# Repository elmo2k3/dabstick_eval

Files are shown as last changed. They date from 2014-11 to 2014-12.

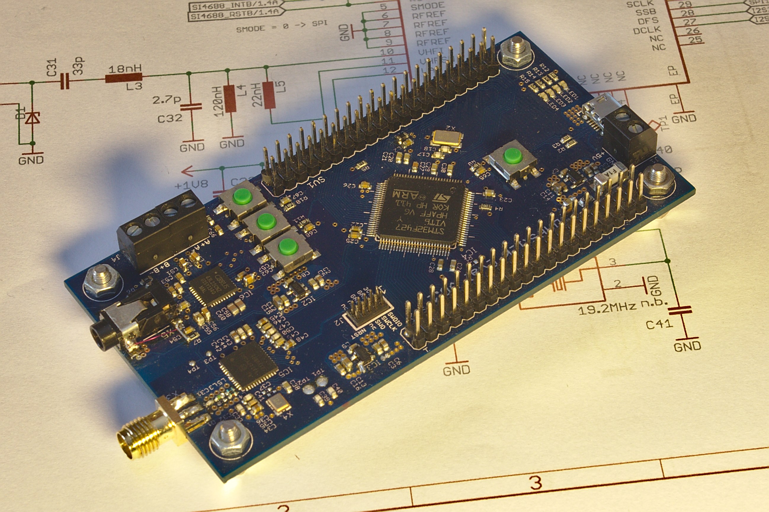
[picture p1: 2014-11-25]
pics/dabstick_v1.jpg

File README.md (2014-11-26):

# DABStick Eval - Experimental board for SI4688 FM/DAB+ receiver with STM32F4 and audio codec

![Image of DABPStick Eval v1 PCB]
(https://github.com/elmo2k3/dabstick_eval/blob/master/pics/dabstick_v1.jpg)

## Warning

This project is still work in progress

## Hardware

* STM32F427VIT6 microcontroller
  * 2MB Flash, 256KB SRAM
  * Up to 180MHz, here 168MHz
* SI4688-A10-GM FM / HD / DAB / DAB + radio receiver
* CS43L22 Audio DAC with integrated class D speaker driver
* General purpose 2x40 pin headers
* Power by USB or screw connector

## Functional overview

![Graph of functional overview]
(https://github.com/elmo2k3/dabstick_eval/blob/master/doc/DABStick_overview.png)

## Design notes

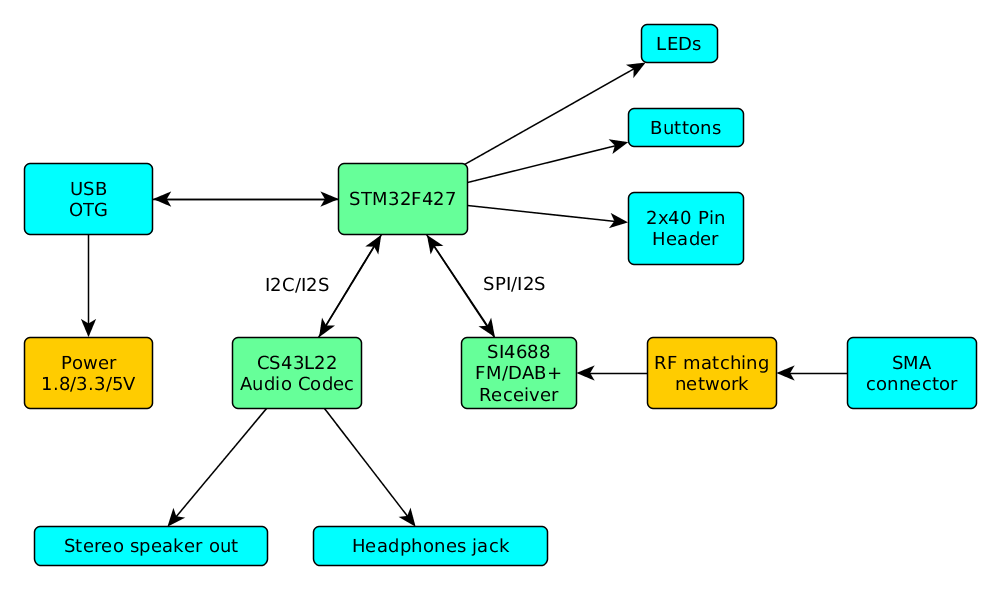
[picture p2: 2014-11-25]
doc/DABStick_overview.png

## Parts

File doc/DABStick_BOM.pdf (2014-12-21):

#name | description | footprint | total_mount_quantity storelocation | suppliers | supplierpartnrs

120NH 110MA 0402 | | L_0402 | 1 | Digikey,Farnell | 490-4091-1-ND,2212473
18NH 300MA 0402 | | L_0402 | 1 | Digikey,Farnell | 490-2626-1-ND,1343084
19.2MHZ,3.2 X 2.5 MM | CRYSTAL 19.2MHZ 10PF SMD | | 1 | Digikey,Farnell | 300-8228-1-ND,1842063
22NH 3% 0402 | | L_0402 | 1 | Digikey,Farnell | 490-6788-1-ND,1711784
8MHz 18PF SMD 5x3.2 | 4 Pads | | 1 | Digikey | 535-9720-1-ND
AKL 059-02 | Anschlussklemme 2-polig, RM3,5 | THT 3.5mm | 2 Pollin Blau 12 Reichelt | AKL 059-02
BLM15HG102SN1D | FILTER CHIP 1000 OHM 250MA 0402 | L_0402 | 1 | Digikey | 490-3999-1-ND
CS43L22-CNZ | | QFN40 | 1 | Digikey | 598-1650-ND
ESD9L5.0ST5G | TVS ESD PROT ELT 5V SOD-923 | SOD923 | 1 Biozym 1 | Digikey,Farnell | ESD9L5.0ST5GOSCT-ND,1651639
Klinkenbuchse 3.5mm PCB LUMBERG - 1503 02 - KUPPLUNG BUCHSE, SMD 3.5MM | 1 | Farnell | 1216979
LD3985M25R | IC REG LDO 2.5V 0.15A SOT23-5 | SOT23-5 | 1 | Digikey | 497-4254-1-ND
LD3985M33R | IC REG LDO 3.3V 0.15A SOT23-5 | SOT23-5 | 1 | Digikey | 497-3504-1-ND
SI4688-A10-GM | | QFN48 | 1 | Arrow | SI4688-A10-GM
STM32F427VIT6 | ARM Mikrocontroller - MCU 32B ARM Cortex-M4 LQFP100 | 1 | Farnell | 2333369
TPS79318DBVR | IC REG LDO 1.8V 0.2A SOT23-5 | SOT23-5 | 1 | Digikey,Farnell | 296-12155-1-ND,1652374

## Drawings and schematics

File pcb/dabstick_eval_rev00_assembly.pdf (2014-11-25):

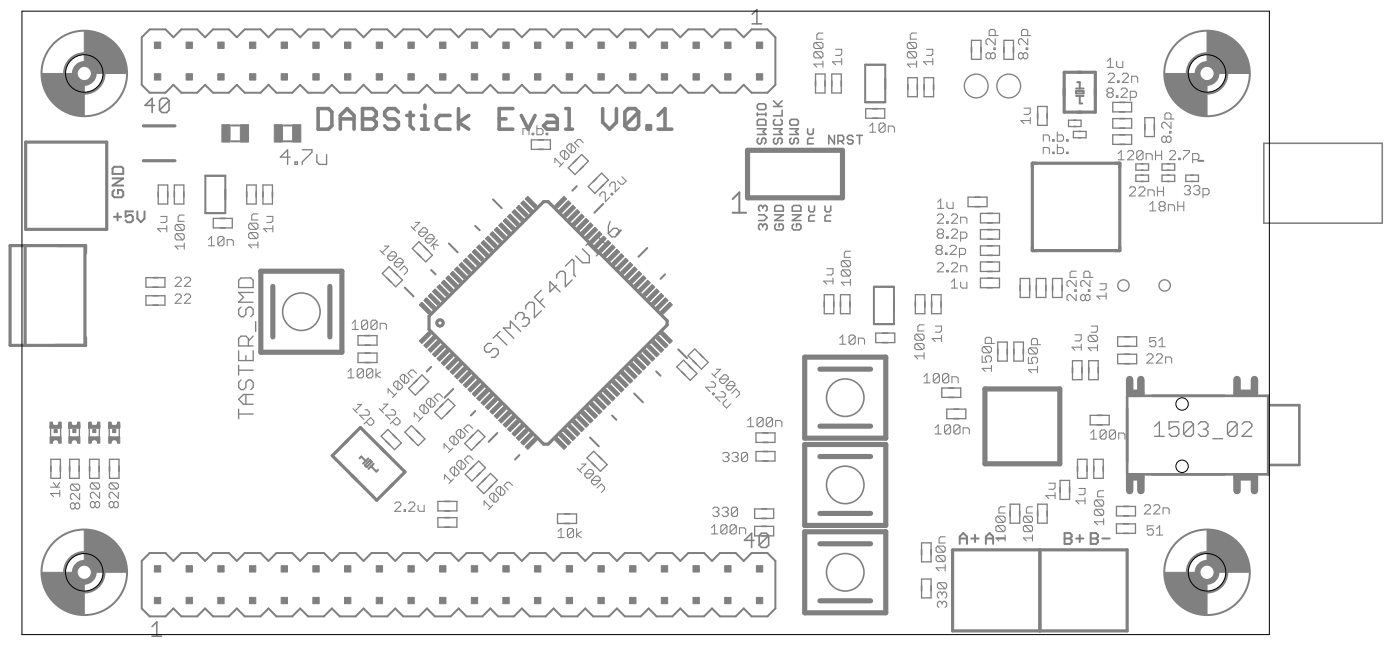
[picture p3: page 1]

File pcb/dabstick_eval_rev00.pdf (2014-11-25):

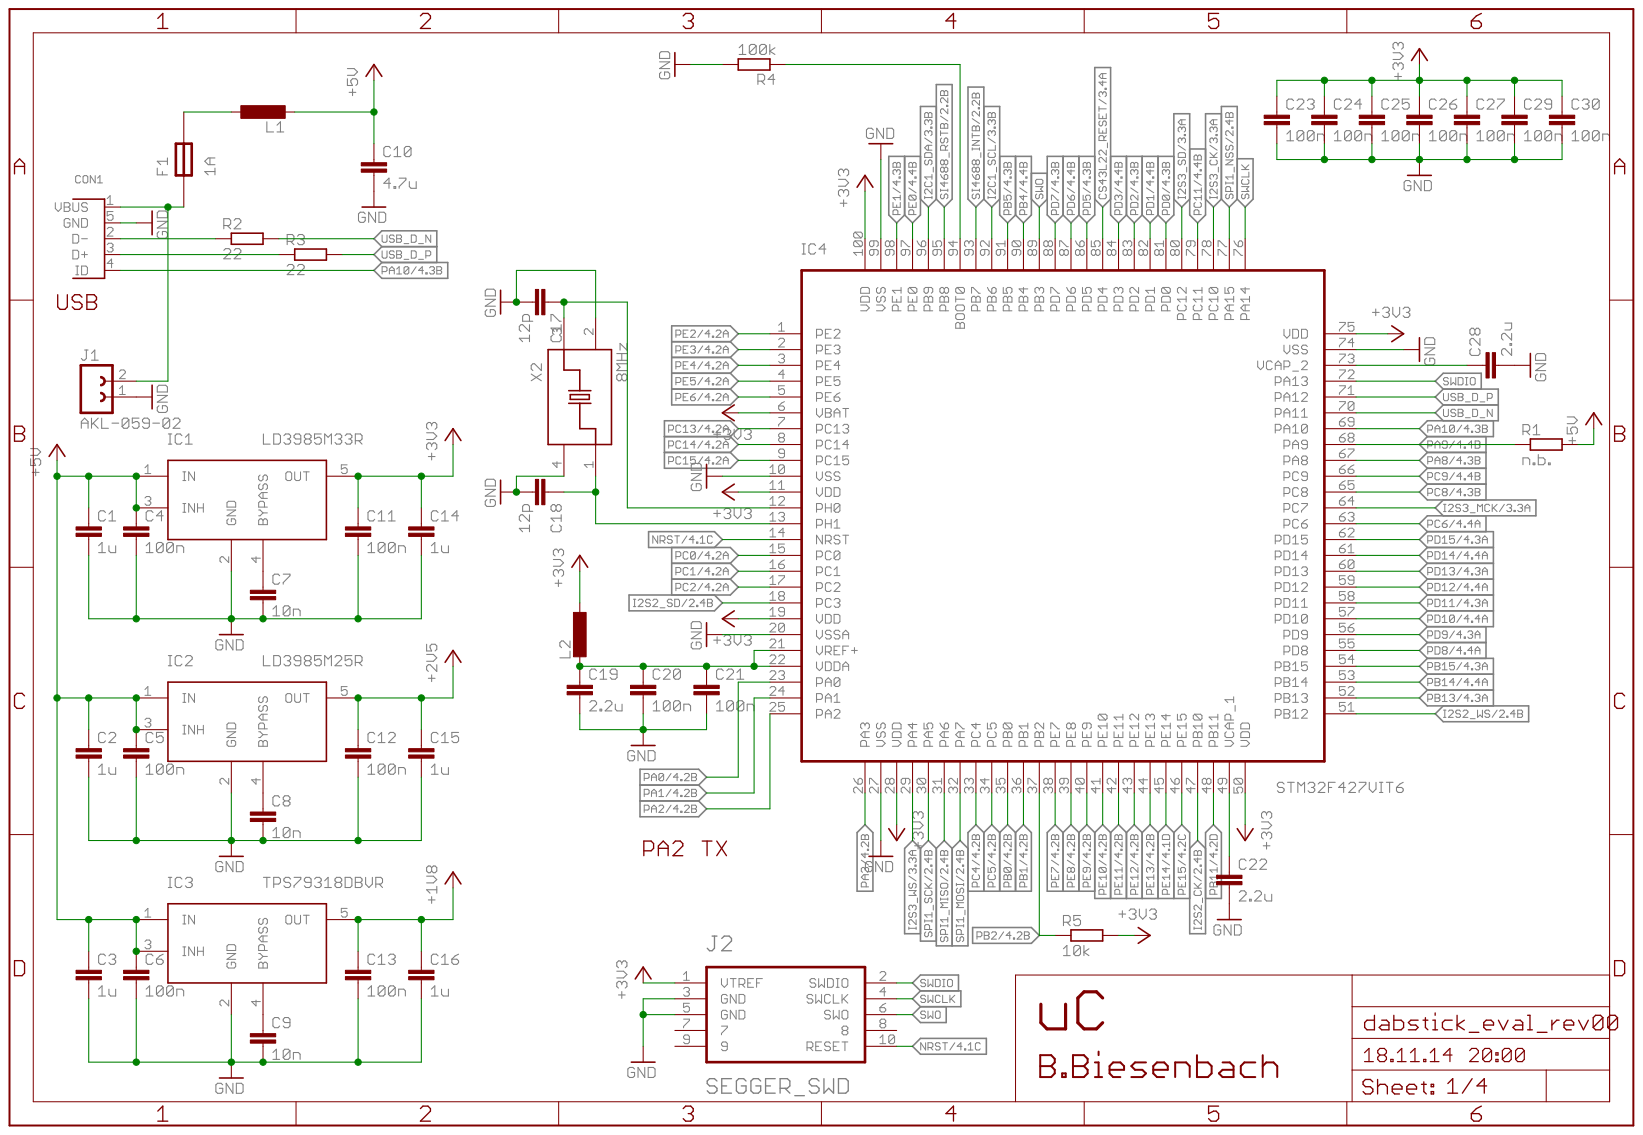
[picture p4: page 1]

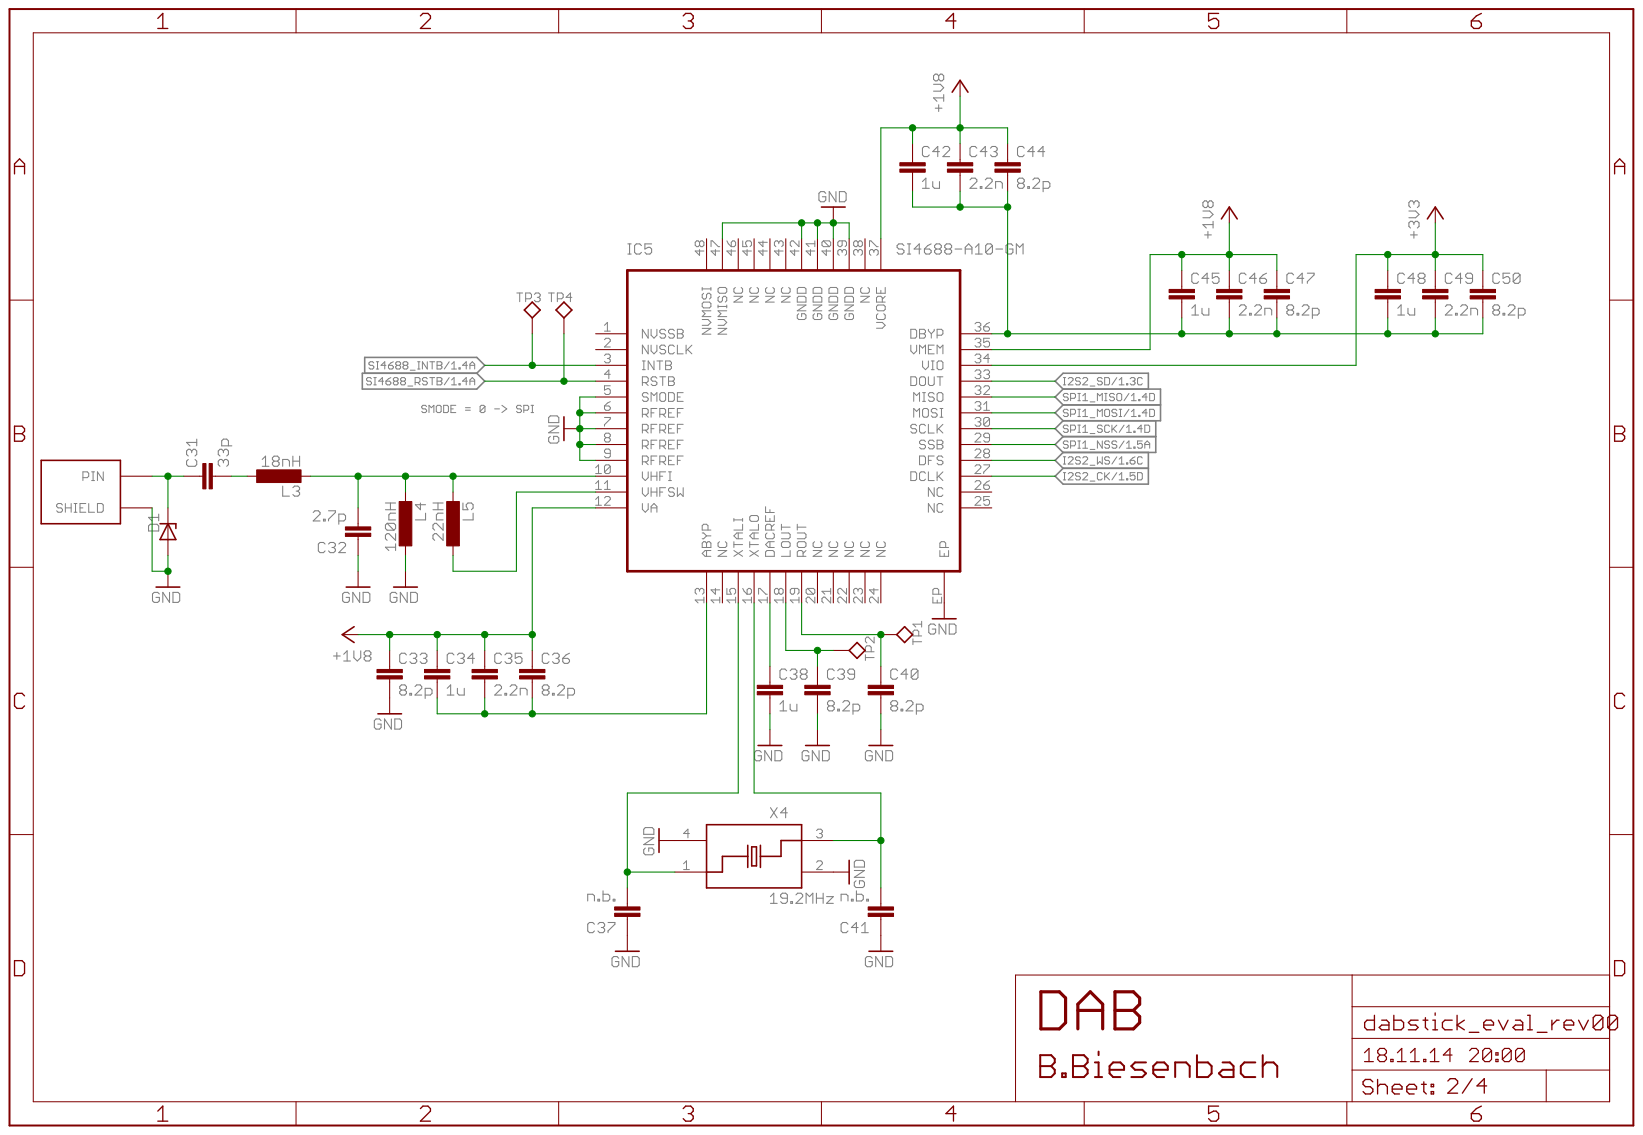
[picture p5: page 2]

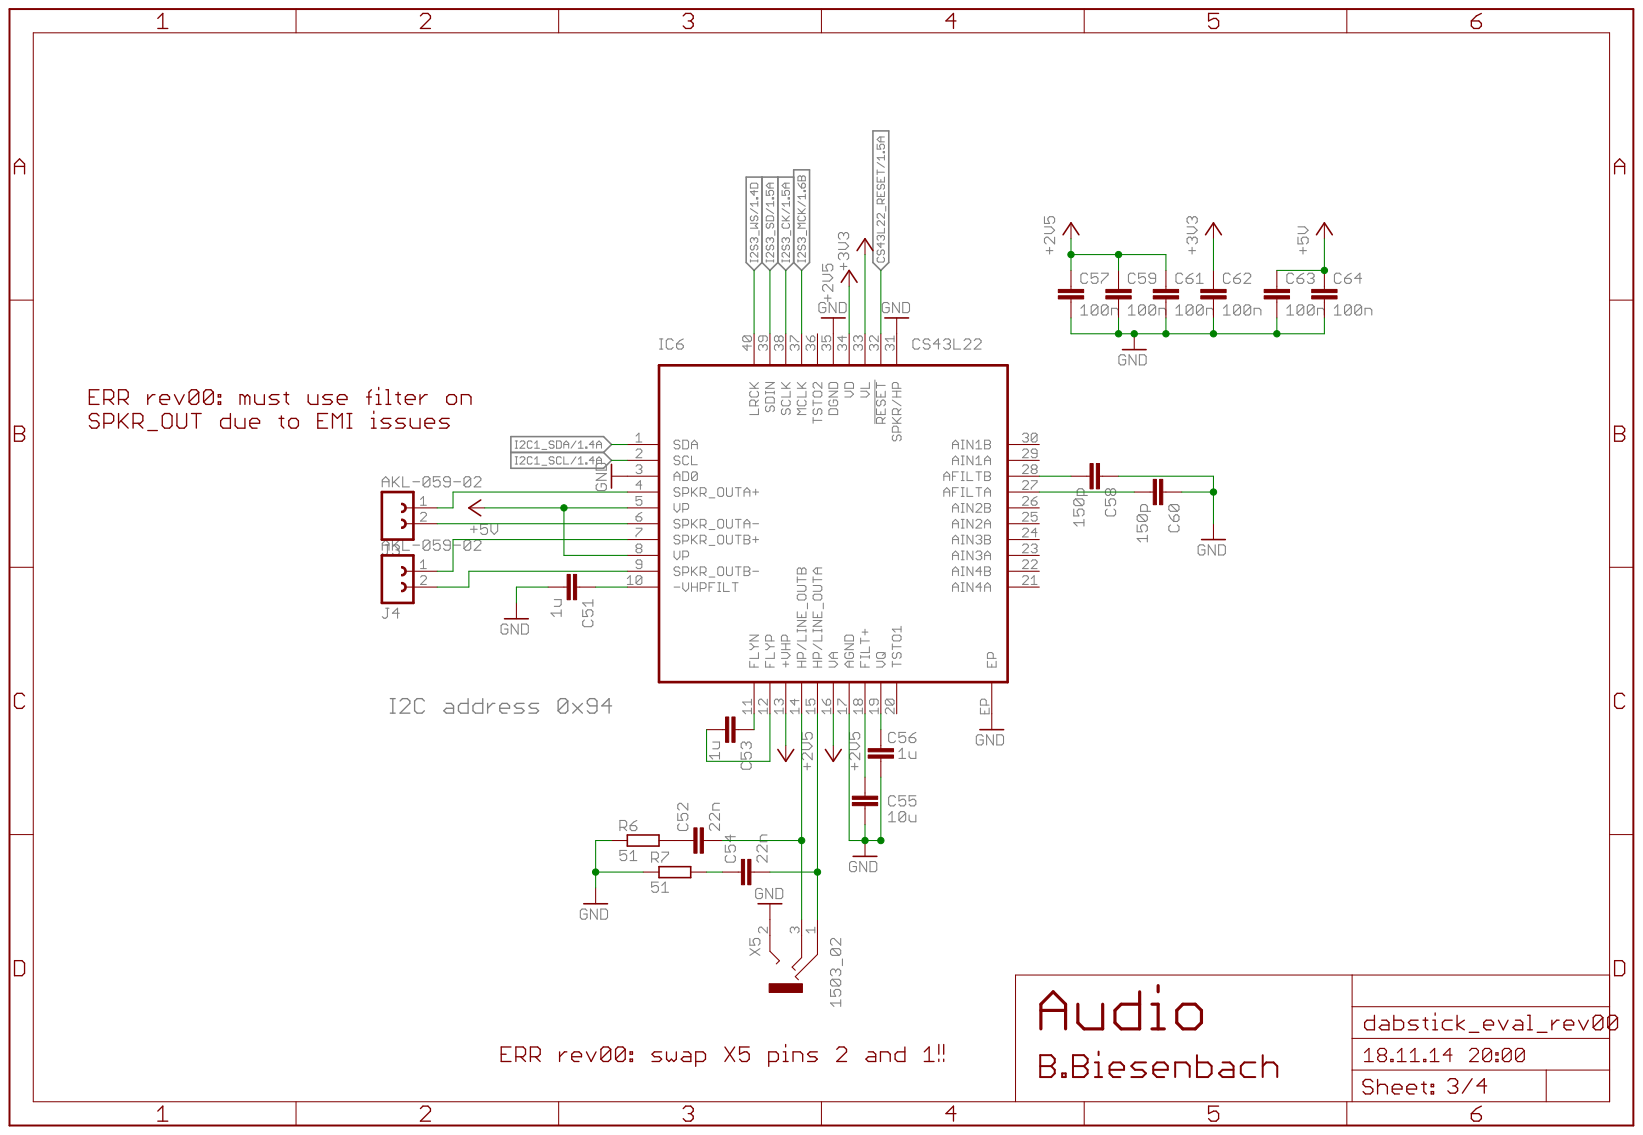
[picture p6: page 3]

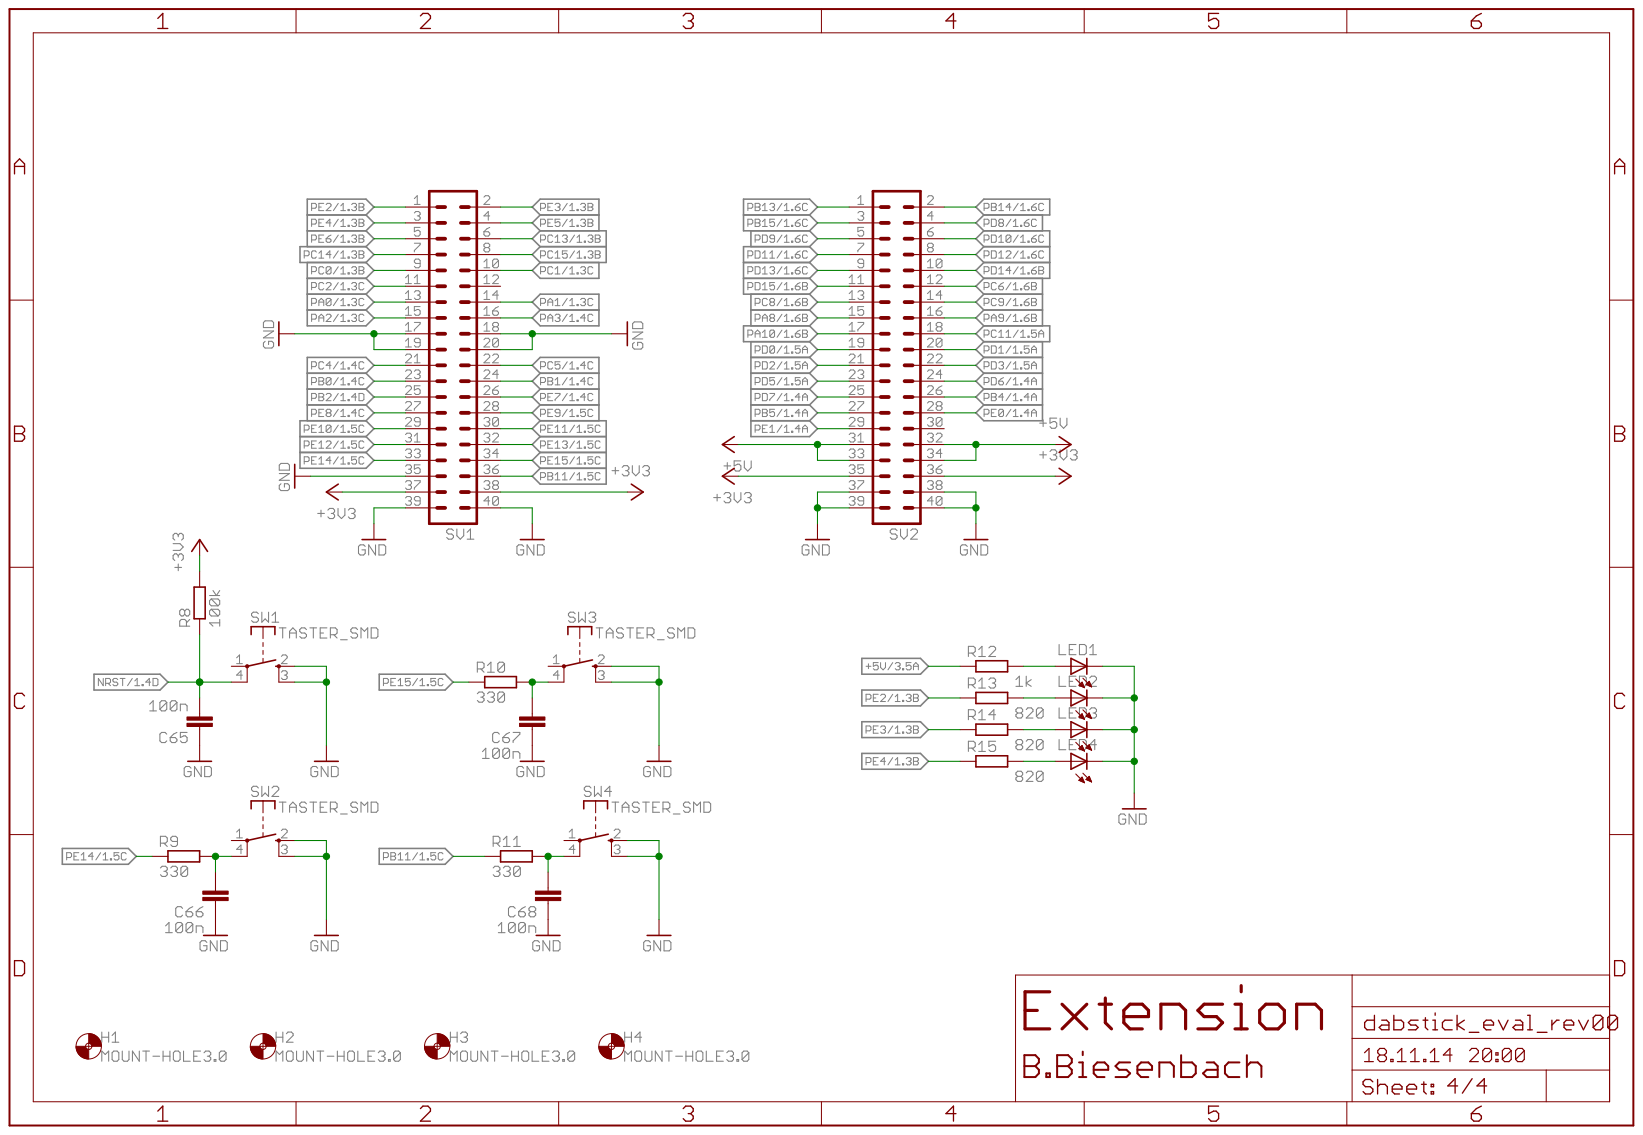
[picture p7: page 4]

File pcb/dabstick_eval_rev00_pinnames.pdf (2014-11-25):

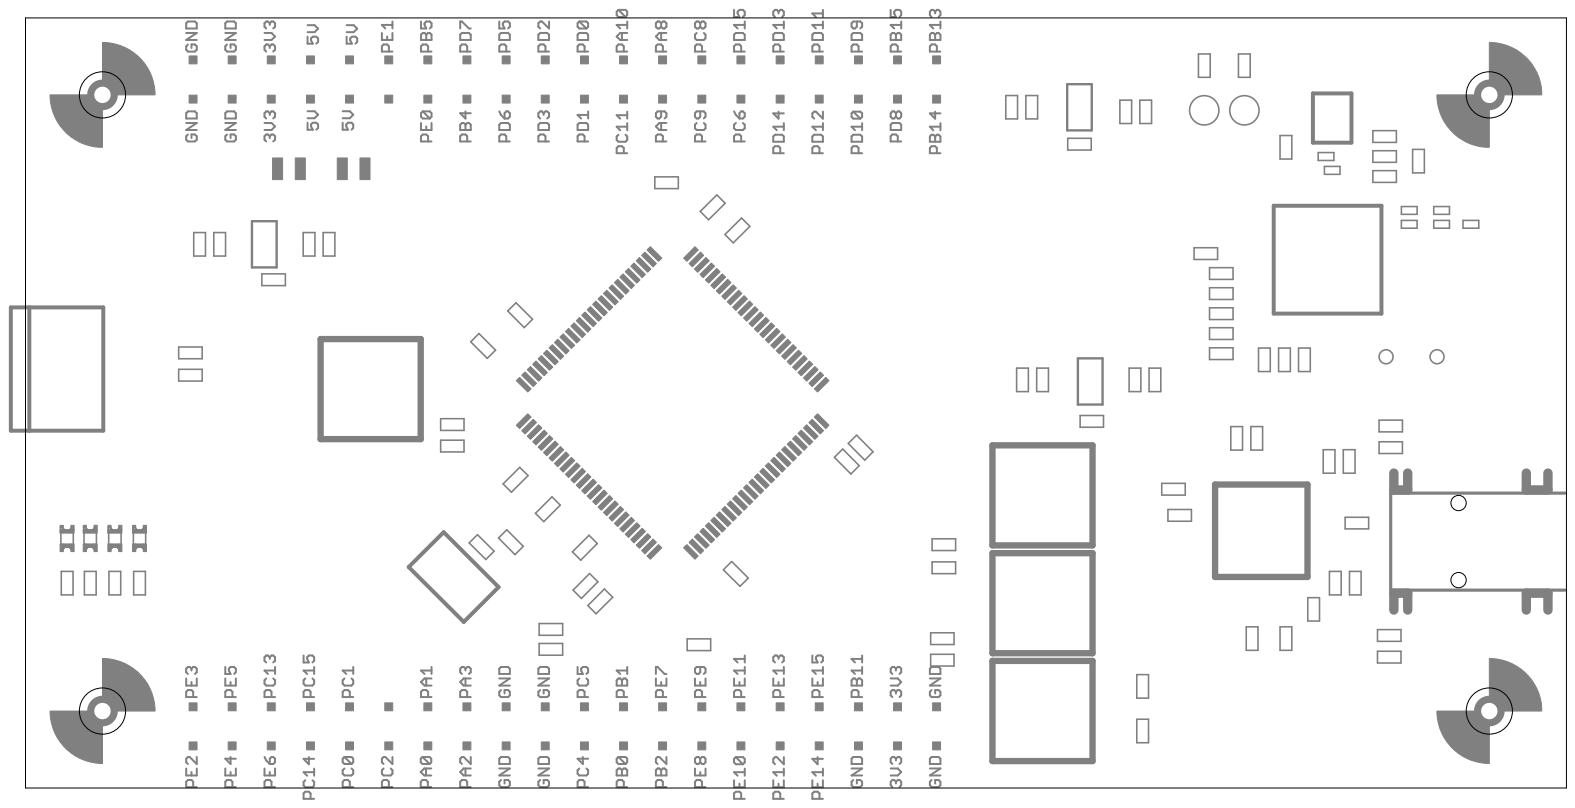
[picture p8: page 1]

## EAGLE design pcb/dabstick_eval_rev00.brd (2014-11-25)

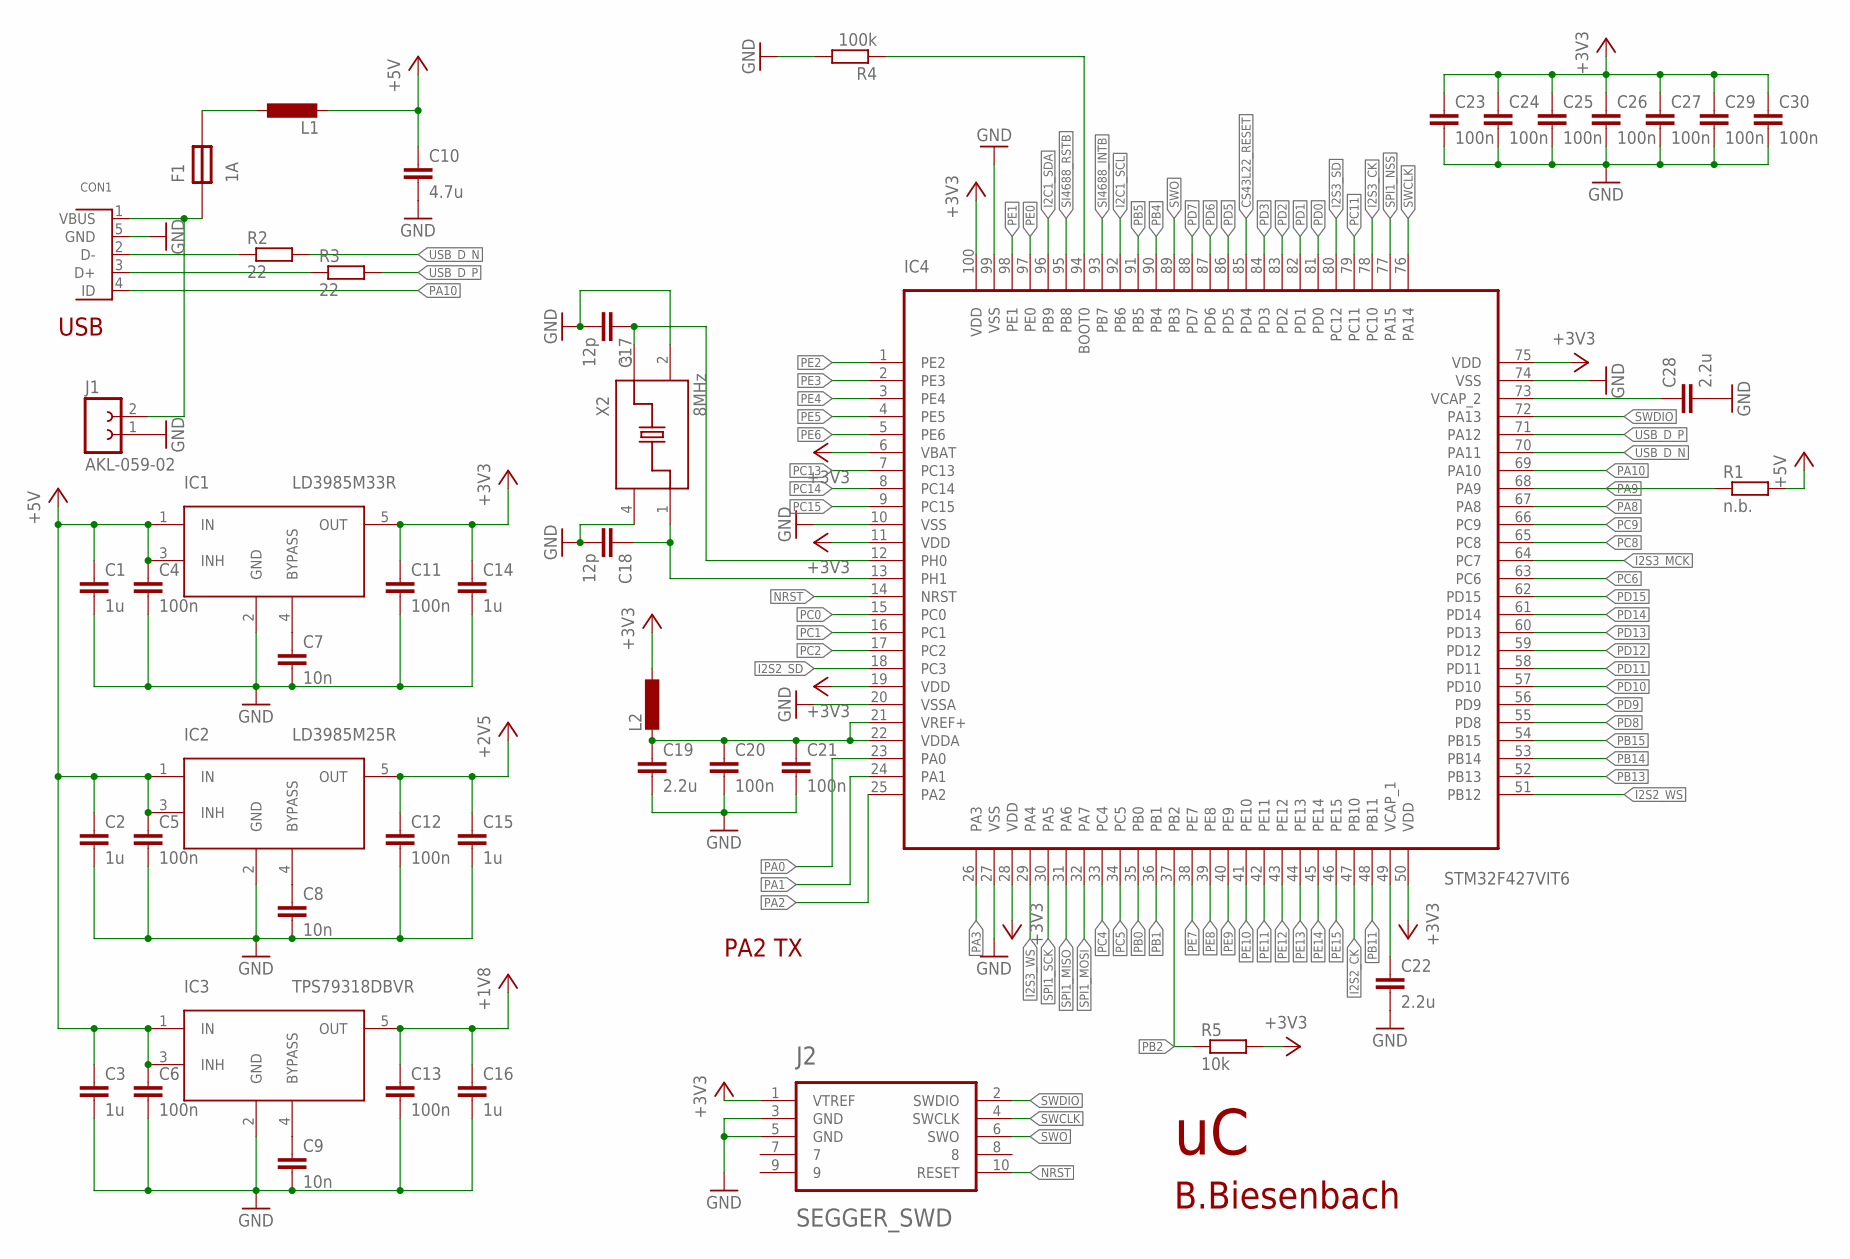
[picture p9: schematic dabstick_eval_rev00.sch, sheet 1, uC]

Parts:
C1, C2, C3, C14, C15, C16: 1u; SMD0603
C4, C5, C6, C11, C12, C13, C20, C21, C23, C24, C25, C26, C27, C29, C30: 100n; SMD0603
C7, C8, C9: 10n; SMD0603
C10: 4.7u; 0805
C17, C18: 12p; SMD0603
C19, C22, C28: 2.2u; SMD0603
CON1: USB; USB-B-MICRO-SMT
F1: 1A; SMD_FUSE
IC1: LD3985M33R; SOT23-5
IC2: LD3985M25R; SOT23-5
IC3: TPS79318DBVR; SOT23-5
IC4: STM32F427VIT6; LQFP100
J1: AKL-059-02
J2: SEGGER_SWD; HEADER_10_1.27
L1: L08050805; 0805
L2: L0603; SMD0603
R1: n.b.; SMD0603
R2, R3: 22; SMD0603
R4: 100k; SMD0603
R5: 10k; SMD0603
X2: 8MHz; XTAL_3.2X5

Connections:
+1V8: C13.1, C16.1, IC3.5 (OUT); also elsewhere on the board
+2V5: C12.1, C15.1, IC2.5 (OUT); also elsewhere on the board
+3V3: C11.1, C14.1, C23.1, C24.1, C25.1, C26.1, C27.1, C29.1, C30.1, IC1.5 (OUT), IC4.6 (VBAT), IC4.11 (VDD), IC4.19 (VDD), IC4.28 (VDD), IC4.50 (VDD), IC4.75 (VDD), IC4.100 (VDD), J2.1 (VTREF), L2.1, R5.2; also elsewhere on the board
+5V: C1.1, C2.1, C3.1, C4.1, C5.1, C6.1, C10.1, IC1.1 (IN), IC1.3 (INH), IC2.1 (IN), IC2.3 (INH), IC3.1 (IN), IC3.3 (INH), L1.2, R1.2; also elsewhere on the board
CS43L22_RESET: IC4.85 (PD4); also elsewhere on the board
GND: C1.2, C2.2, C3.2, C4.2, C5.2, C6.2, C7.2, C8.2, C9.2, C10.2, C11.2, C12.2, C13.2, C14.2, C15.2, C16.2, C17.2, C18.2, C19.2, C20.2, C21.2, C22.2, C23.2, C24.2, C25.2, C26.2, C27.2, C28.2, C29.2, C30.2, CON1.5 (GND), IC1.2 (GND), IC2.2 (GND), IC3.2 (GND), IC4.10 (VSS), IC4.20 (VSSA), IC4.27 (VSS), IC4.74 (VSS), IC4.99 (VSS), J1.1, J2.3 (GND), J2.5 (GND), R4.2, X2.2 (GND), X2.4 (GND); also elsewhere on the board
I2C1_SCL: IC4.92 (PB6); also elsewhere on the board
I2C1_SDA: IC4.96 (PB9); also elsewhere on the board
I2S2_CK: IC4.47 (PB10); also elsewhere on the board
I2S2_SD: IC4.18 (PC3); also elsewhere on the board
I2S2_WS: IC4.51 (PB12); also elsewhere on the board
I2S3_CK: IC4.78 (PC10); also elsewhere on the board
I2S3_MCK: IC4.64 (PC7); also elsewhere on the board
I2S3_SD: IC4.80 (PC12); also elsewhere on the board
I2S3_WS: IC4.29 (PA4); also elsewhere on the board
unnamed: C7.1, IC1.4 (BYPASS)
unnamed: C8.1, IC2.4 (BYPASS)
unnamed: C9.1, IC3.4 (BYPASS)
unnamed: C19.1, C20.1, C21.1, IC4.21 (VREF+), IC4.22 (VDDA), L2.2
unnamed: C28.1, IC4.73 (VCAP_2)
unnamed: C22.1, IC4.49 (VCAP_1)
unnamed: CON1.3 (D+), R3.1
unnamed: CON1.2 (D-), R2.1
unnamed: C18.1, IC4.13 (PH1), X2.1
unnamed: C17.1, IC4.12 (PH0), X2.3
unnamed: IC4.94 (BOOT0), R4.1
unnamed: F1.P$2, L1.1
unnamed: CON1.1 (VBUS), F1.P$1, J1.2
NRST: IC4.14 (NRST), J2.10 (RESET); also elsewhere on the board
PA0: IC4.23 (PA0); also elsewhere on the board
PA1: IC4.24 (PA1); also elsewhere on the board
PA2: IC4.25 (PA2); also elsewhere on the board
PA3: IC4.26 (PA3); also elsewhere on the board
PA8: IC4.67 (PA8); also elsewhere on the board
PA9: IC4.68 (PA9), R1.1; also elsewhere on the board
PA10: CON1.4 (ID), IC4.69 (PA10); also elsewhere on the board
PB0: IC4.35 (PB0); also elsewhere on the board
PB1: IC4.36 (PB1); also elsewhere on the board
PB2: IC4.37 (PB2), R5.1; also elsewhere on the board
PB4: IC4.90 (PB4); also elsewhere on the board
PB5: IC4.91 (PB5); also elsewhere on the board
PB11: IC4.48 (PB11); also elsewhere on the board
PB13: IC4.52 (PB13); also elsewhere on the board
PB14: IC4.53 (PB14); also elsewhere on the board
PB15: IC4.54 (PB15); also elsewhere on the board
PC0: IC4.15 (PC0); also elsewhere on the board
PC1: IC4.16 (PC1); also elsewhere on the board
PC2: IC4.17 (PC2); also elsewhere on the board
PC4: IC4.33 (PC4); also elsewhere on the board
PC5: IC4.34 (PC5); also elsewhere on the board
PC6: IC4.63 (PC6); also elsewhere on the board
PC8: IC4.65 (PC8); also elsewhere on the board
PC9: IC4.66 (PC9); also elsewhere on the board
PC11: IC4.79 (PC11); also elsewhere on the board
PC13: IC4.7 (PC13); also elsewhere on the board
PC14: IC4.8 (PC14); also elsewhere on the board
PC15: IC4.9 (PC15); also elsewhere on the board
PD0: IC4.81 (PD0); also elsewhere on the board
PD1: IC4.82 (PD1); also elsewhere on the board
PD2: IC4.83 (PD2); also elsewhere on the board
PD3: IC4.84 (PD3); also elsewhere on the board
PD5: IC4.86 (PD5); also elsewhere on the board
PD6: IC4.87 (PD6); also elsewhere on the board
PD7: IC4.88 (PD7); also elsewhere on the board
PD8: IC4.55 (PD8); also elsewhere on the board
PD9: IC4.56 (PD9); also elsewhere on the board
PD10: IC4.57 (PD10); also elsewhere on the board
PD11: IC4.58 (PD11); also elsewhere on the board
PD12: IC4.59 (PD12); also elsewhere on the board
PD13: IC4.60 (PD13); also elsewhere on the board
PD14: IC4.61 (PD14); also elsewhere on the board
PD15: IC4.62 (PD15); also elsewhere on the board
PE0: IC4.97 (PE0); also elsewhere on the board
PE1: IC4.98 (PE1); also elsewhere on the board
PE2: IC4.1 (PE2); also elsewhere on the board
PE3: IC4.2 (PE3); also elsewhere on the board
PE4: IC4.3 (PE4); also elsewhere on the board
PE5: IC4.4 (PE5); also elsewhere on the board
PE6: IC4.5 (PE6); also elsewhere on the board
PE7: IC4.38 (PE7); also elsewhere on the board
PE8: IC4.39 (PE8); also elsewhere on the board
PE9: IC4.40 (PE9); also elsewhere on the board
PE10: IC4.41 (PE10); also elsewhere on the board
PE11: IC4.42 (PE11); also elsewhere on the board
PE12: IC4.43 (PE12); also elsewhere on the board
PE13: IC4.44 (PE13); also elsewhere on the board
PE14: IC4.45 (PE14); also elsewhere on the board
PE15: IC4.46 (PE15); also elsewhere on the board
SI4688_INTB: IC4.93 (PB7); also elsewhere on the board
SI4688_RSTB: IC4.95 (PB8); also elsewhere on the board
SPI1_MISO: IC4.31 (PA6); also elsewhere on the board
SPI1_MOSI: IC4.32 (PA7); also elsewhere on the board
SPI1_NSS: IC4.77 (PA15); also elsewhere on the board
SPI1_SCK: IC4.30 (PA5); also elsewhere on the board
SWCLK: IC4.76 (PA14), J2.4 (SWCLK)
SWDIO: IC4.72 (PA13), J2.2 (SWDIO)
SWO: IC4.89 (PB3), J2.6 (SWO)
USB_D_N: IC4.70 (PA11), R2.2
USB_D_P: IC4.71 (PA12), R3.2

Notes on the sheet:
PA2 TX
B.Biesenbach

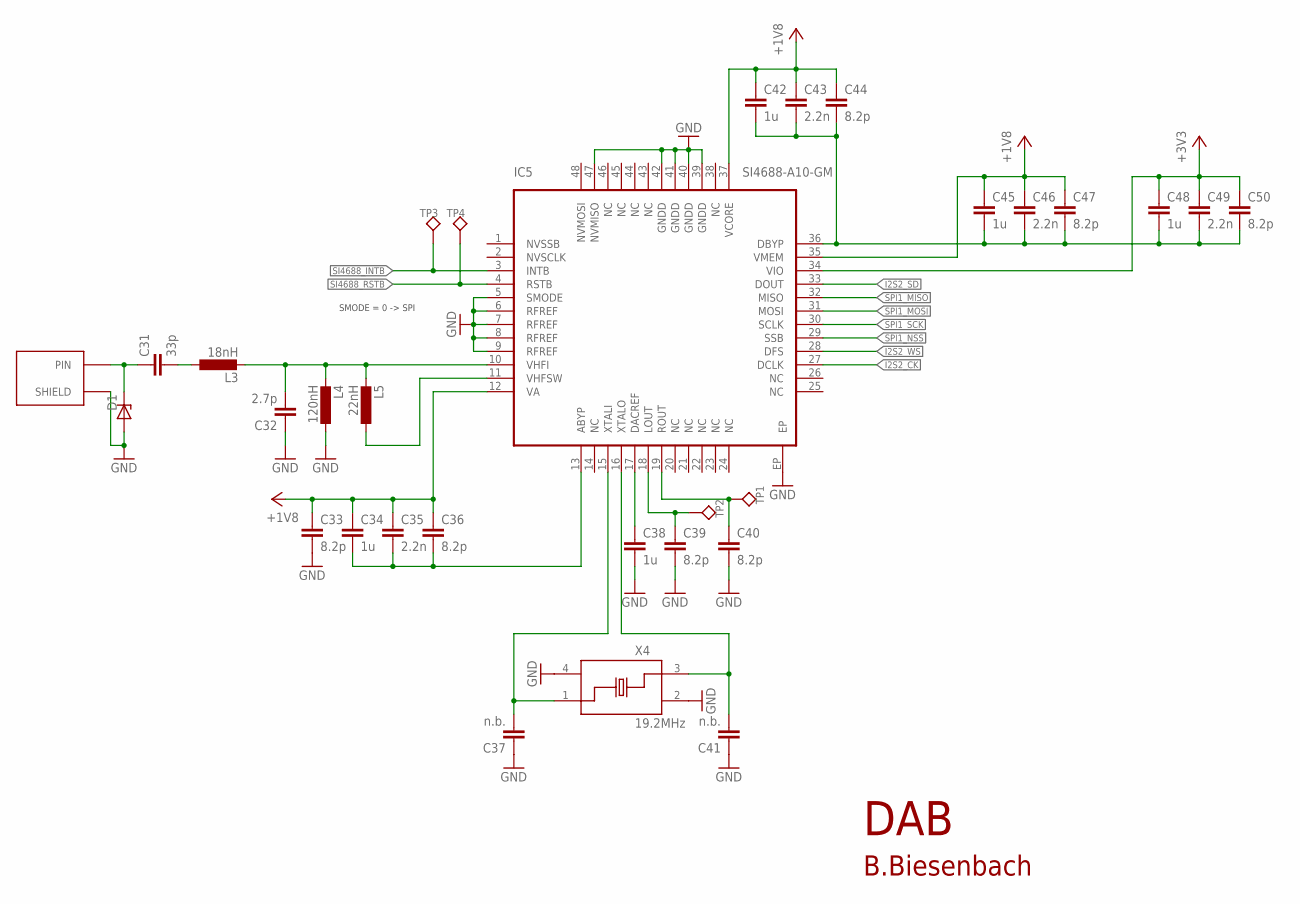
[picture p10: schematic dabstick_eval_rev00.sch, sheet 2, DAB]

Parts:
C31: 33p; SMD0402
C32: 2.7p; SMD0402
C33, C36, C39, C40, C44, C47, C50: 8.2p; SMD0603
C34, C38, C42, C45, C48: 1u; SMD0603
C35, C43, C46, C49: 2.2n; SMD0603
C37, C41: n.b.; SMD0402
D1: ESD9L5.0; SOD923
IC5: SI4688-A10-GM; QFN48
L3: 18nH; SMD0402
L4: 120nH; SMD0402
L5: 22nH; SMD0402
TP1, TP2: TP-2-MM
TP3, TP4: TP-1-MM
X3: SMA_LP_1.57MM
X4: 19.2MHz; XTAL_3.2X2.5

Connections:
+1V8: C33.1, C34.1, C35.1, C36.1, C42.1, C43.1, C44.1, C45.1, C46.1, C47.1, IC5.12 (VA), IC5.35 (VMEM), IC5.37 (VCORE); also elsewhere on the board
+3V3: C48.1, C49.1, C50.1, IC5.34 (VIO); also elsewhere on the board
GND: C32.1, C33.2, C37.1, C38.2, C39.2, C40.2, C41.1, D1.A, IC5.5 (SMODE), IC5.6 (RFREF), IC5.7 (RFREF), IC5.8 (RFREF), IC5.9 (RFREF), IC5.39 (GNDD), IC5.40 (GNDD), IC5.41 (GNDD), IC5.42 (GNDD), IC5.47 (NVMISO), IC5.EP, L4.1, X3.GND (SHIELD), X3.GND@1 (SHIELD), X3.GND@2 (SHIELD), X3.GND@3 (SHIELD), X4.2 (GND), X4.4 (GND); also elsewhere on the board
I2S2_CK: IC5.27 (DCLK); also elsewhere on the board
I2S2_SD: IC5.33 (DOUT); also elsewhere on the board
I2S2_WS: IC5.28 (DFS); also elsewhere on the board
unnamed: C31.2, L3.1
unnamed: C32.2, IC5.10 (VHFI), L3.2, L4.2, L5.2
unnamed: IC5.11 (VHFSW), L5.1
unnamed: C34.2, C35.2, C36.2, IC5.13 (ABYP)
unnamed: C42.2, C43.2, C44.2, C45.2, C46.2, C47.2, C48.2, C49.2, C50.2, IC5.36 (DBYP)
unnamed: C37.2, IC5.15 (XTALI), X4.1
unnamed: C41.2, IC5.16 (XTALO), X4.3
unnamed: C38.1, IC5.17 (DACREF)
RF_IN: C31.1, D1.K (C), X3.PIN
SI4688_INTB: IC5.3 (INTB), TP3.1; also elsewhere on the board
SI4688_LOUT: C39.1, IC5.18 (LOUT), TP2.P$1
SI4688_ROUT: C40.1, IC5.19 (ROUT), TP1.P$1
SI4688_RSTB: IC5.4 (RSTB), TP4.1; also elsewhere on the board
SPI1_MISO: IC5.32 (MISO); also elsewhere on the board
SPI1_MOSI: IC5.31 (MOSI); also elsewhere on the board
SPI1_NSS: IC5.29 (SSB); also elsewhere on the board
SPI1_SCK: IC5.30 (SCLK); also elsewhere on the board

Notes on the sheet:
DAB
SMODE = 0 -> SPI
B.Biesenbach

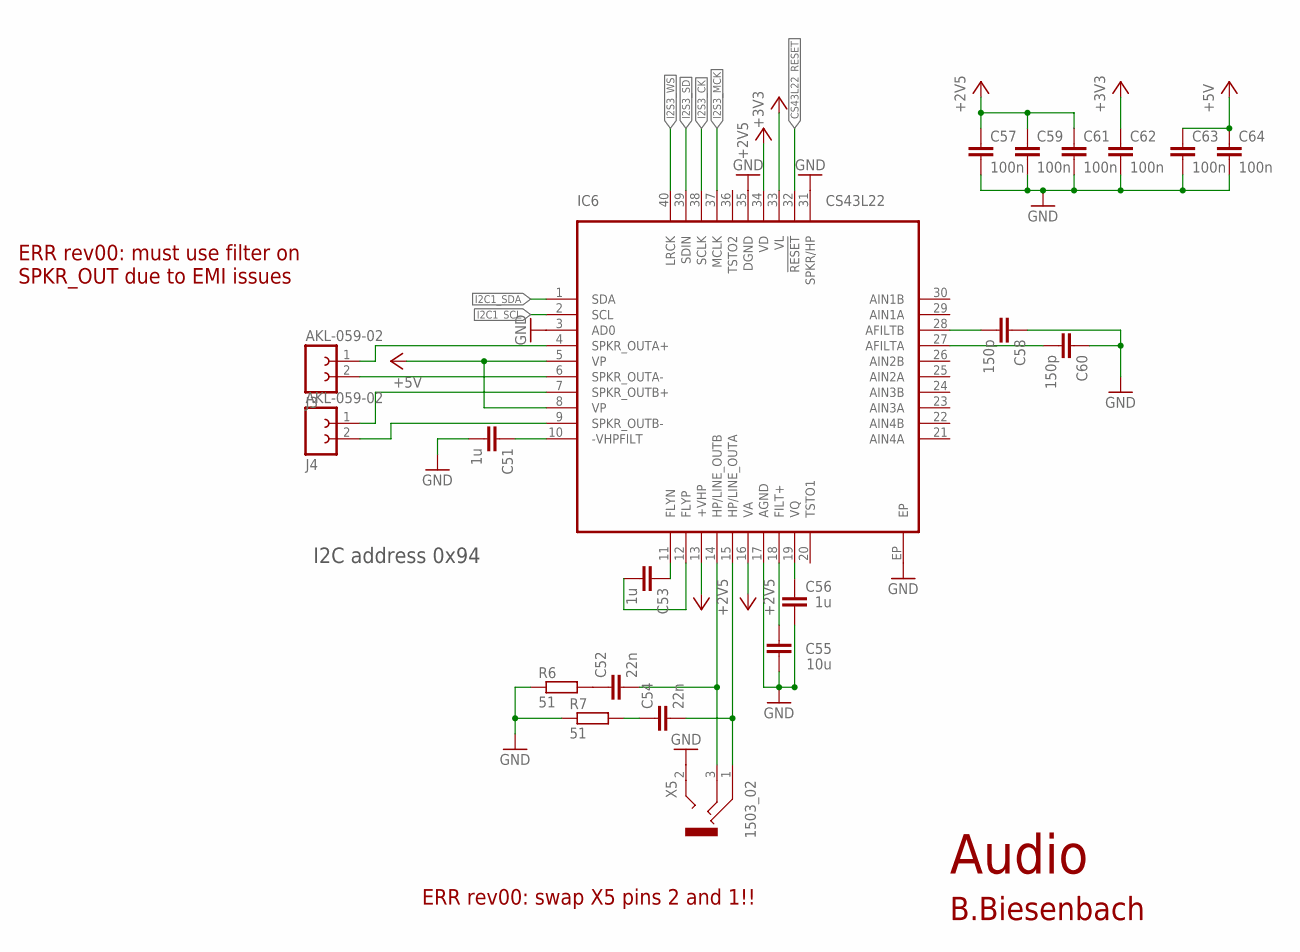
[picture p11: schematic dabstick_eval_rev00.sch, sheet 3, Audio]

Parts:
C51, C53, C56: 1u; SMD0603
C52, C54: 22n; SMD0603
C55: 10u; SMD0603
C57, C59, C61, C62, C63, C64: 100n; SMD0603
C58, C60: 150p; SMD0603
IC6: CS43L22; QFN40
J3, J4: AKL-059-02
R6, R7: 51; SMD0603
X5: 1503_02

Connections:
+2V5: C57.1, C59.1, C61.1, IC6.13 (+VHP), IC6.16 (VA), IC6.34 (VD); also elsewhere on the board
+3V3: C62.1, IC6.33 (VL); also elsewhere on the board
+5V: C63.1, C64.1, IC6.5 (VP), IC6.8 (VP); also elsewhere on the board
CS43L22_RESET: IC6.32 (!RESET); also elsewhere on the board
GND: C51.2, C55.1, C56.1, C57.2, C58.1, C59.2, C60.1, C61.2, C62.2, C63.2, C64.2, IC6.3 (AD0), IC6.17 (AGND), IC6.31 (SPKR/HP), IC6.35 (DGND), IC6.EP, R6.1, R7.1, X5.2; also elsewhere on the board
I2C1_SCL: IC6.2 (SCL); also elsewhere on the board
I2C1_SDA: IC6.1 (SDA); also elsewhere on the board
I2S3_CK: IC6.38 (SCLK); also elsewhere on the board
I2S3_MCK: IC6.37 (MCLK); also elsewhere on the board
I2S3_SD: IC6.39 (SDIN); also elsewhere on the board
I2S3_WS: IC6.40 (LRCK); also elsewhere on the board
unnamed: IC6.4 (SPKR_OUTA+), J3.1
unnamed: IC6.6 (SPKR_OUTA-), J3.2
unnamed: IC6.7 (SPKR_OUTB+), J4.1
unnamed: IC6.9 (SPKR_OUTB-), J4.2
unnamed: C54.2, IC6.15 (HP/LINE_OUTA), X5.1
unnamed: C52.2, IC6.14 (HP/LINE_OUTB), X5.3
unnamed: C52.1, R6.2
unnamed: C54.1, R7.2
unnamed: C56.2, IC6.19 (VQ)
unnamed: C55.2, IC6.18 (FILT+)
unnamed: C58.2, IC6.28 (AFILTB)
unnamed: C60.2, IC6.27 (AFILTA)
unnamed: C51.1, IC6.10 (-VHPFILT)
unnamed: C53.1, IC6.11 (FLYN)
unnamed: C53.2, IC6.12 (FLYP)

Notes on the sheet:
Audio
I2C address 0x94
B.Biesenbach
ERR rev00: swap X5 pins 2 and 1!!
ERR rev00: must use filter on SPKR_OUT due to EMI issues

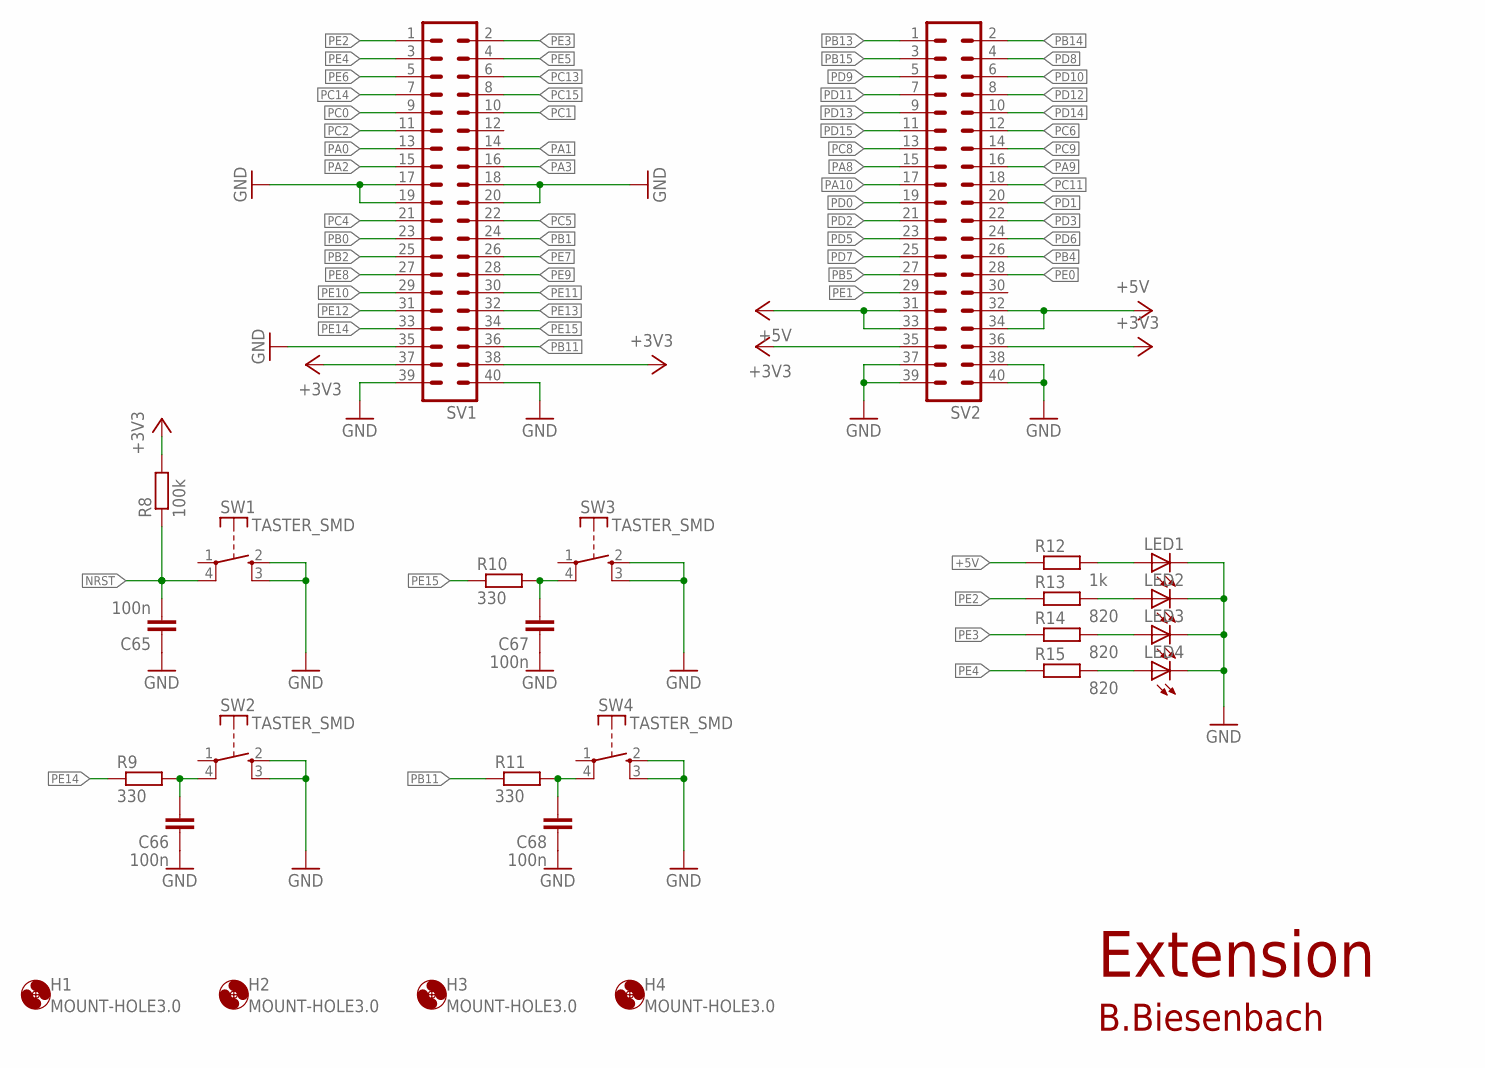
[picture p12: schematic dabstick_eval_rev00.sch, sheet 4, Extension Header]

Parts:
C65, C66, C67, C68: 100n; SMD0603
H1, H2, H3, H4: MOUNT-HOLE3.0; 3,0
LED1, LED2, LED3, LED4: LEDCHIPLED_0603; CHIPLED_0603
R8: 100k; SMD0603
R9, R10, R11: 330; SMD0603
R12: 1k; SMD0603
R13, R14, R15: 820; SMD0603
SV1, SV2: MA20-2
SW1, SW2, SW3, SW4: TASTER_SMD; TASTER_SMD_ALPS

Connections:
+3V3: R8.2, SV1.37, SV1.38, SV2.35, SV2.36; also elsewhere on the board
+5V: R12.1, SV2.31, SV2.32, SV2.33, SV2.34; also elsewhere on the board
GND: C65.1, C66.1, C67.1, C68.1, LED1.C, LED2.C, LED3.C, LED4.C, SV1.17, SV1.18, SV1.19, SV1.20, SV1.35, SV1.39, SV1.40, SV2.37, SV2.38, SV2.39, SV2.40, SW1.2 (S), SW1.3 (S), SW2.2 (S), SW2.3 (S), SW3.2 (S), SW3.3 (S), SW4.2 (S), SW4.3 (S); also elsewhere on the board
unnamed: C66.2, R9.2, SW2.4
unnamed: C68.2, R11.2, SW4.4
unnamed: C67.2, R10.2, SW3.4
unnamed: LED1.A, R12.2
unnamed: LED2.A, R13.2
unnamed: LED3.A, R14.2
unnamed: LED4.A, R15.2
NRST: C65.2, R8.1, SW1.4; also elsewhere on the board
PA0: SV1.13; also elsewhere on the board
PA1: SV1.14; also elsewhere on the board
PA2: SV1.15; also elsewhere on the board
PA3: SV1.16; also elsewhere on the board
PA8: SV2.15; also elsewhere on the board
PA9: SV2.16; also elsewhere on the board
PA10: SV2.17; also elsewhere on the board
PB0: SV1.23; also elsewhere on the board
PB1: SV1.24; also elsewhere on the board
PB2: SV1.25; also elsewhere on the board
PB4: SV2.26; also elsewhere on the board
PB5: SV2.27; also elsewhere on the board
PB11: R11.1, SV1.36; also elsewhere on the board
PB13: SV2.1; also elsewhere on the board
PB14: SV2.2; also elsewhere on the board
PB15: SV2.3; also elsewhere on the board
PC0: SV1.9; also elsewhere on the board
PC1: SV1.10; also elsewhere on the board
PC2: SV1.11; also elsewhere on the board
PC4: SV1.21; also elsewhere on the board
PC5: SV1.22; also elsewhere on the board
PC6: SV2.12; also elsewhere on the board
PC8: SV2.13; also elsewhere on the board
PC9: SV2.14; also elsewhere on the board
PC11: SV2.18; also elsewhere on the board
PC13: SV1.6; also elsewhere on the board
PC14: SV1.7; also elsewhere on the board
PC15: SV1.8; also elsewhere on the board
PD0: SV2.19; also elsewhere on the board
PD1: SV2.20; also elsewhere on the board
PD2: SV2.21; also elsewhere on the board
PD3: SV2.22; also elsewhere on the board
PD5: SV2.23; also elsewhere on the board
PD6: SV2.24; also elsewhere on the board
PD7: SV2.25; also elsewhere on the board
PD8: SV2.4; also elsewhere on the board
PD9: SV2.5; also elsewhere on the board
PD10: SV2.6; also elsewhere on the board
PD11: SV2.7; also elsewhere on the board
PD12: SV2.8; also elsewhere on the board
PD13: SV2.9; also elsewhere on the board
PD14: SV2.10; also elsewhere on the board
PD15: SV2.11; also elsewhere on the board
PE0: SV2.28; also elsewhere on the board
PE1: SV2.29; also elsewhere on the board
PE2: R13.1, SV1.1; also elsewhere on the board
PE3: R14.1, SV1.2; also elsewhere on the board
PE4: R15.1, SV1.3; also elsewhere on the board
PE5: SV1.4; also elsewhere on the board
PE6: SV1.5; also elsewhere on the board
PE7: SV1.26; also elsewhere on the board
PE8: SV1.27; also elsewhere on the board
PE9: SV1.28; also elsewhere on the board
PE10: SV1.29; also elsewhere on the board
PE11: SV1.30; also elsewhere on the board
PE12: SV1.31; also elsewhere on the board
PE13: SV1.32; also elsewhere on the board
PE14: R9.1, SV1.33; also elsewhere on the board
PE15: R10.1, SV1.34; also elsewhere on the board

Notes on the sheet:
Extension
B.Biesenbach

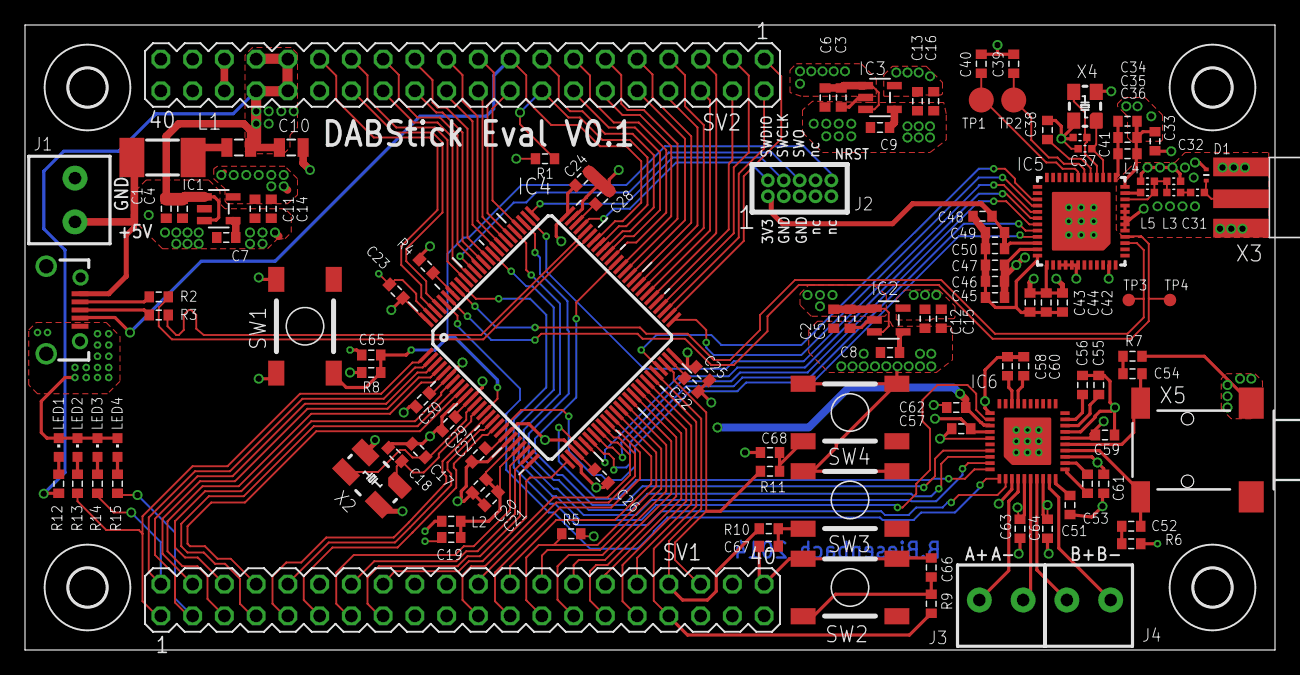
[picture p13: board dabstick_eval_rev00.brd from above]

Board: 4 copper layers, 100.0 x 50.0 mm, 123 parts (0 on the bottom side), 132 nets.

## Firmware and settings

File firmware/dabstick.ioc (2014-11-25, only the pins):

Mcu.UserName=STM32F427VITx
PA11.Signal=USB_OTG_FS_DM
PA12.Signal=USB_OTG_FS_DP
PA13.Signal=SYS_JTMS-SWDIO
PA14.Signal=SYS_JTCK-SWCLK
PA15.GPIO_Label=SI46XX_NSS
PA15.Signal=GPIO_Output
PA2.Signal=USART2_TX
PA3.Signal=USART2_RX
PA4.Signal=I2S3_WS
PA5.Signal=SPI1_SCK
PA6.Signal=SPI1_MISO
PA7.Signal=SPI1_MOSI
PB0.GPIO_Label=ROT_BT
PB0.Signal=GPIO_Input
PB1.Signal=S_TIM3_CH4
PB10.Signal=I2S2_CK
PB11.GPIO_Label=SW4
PB11.Signal=GPIO_Input
PB12.Signal=I2S2_WS
PB13.Signal=GPIO_Output
PB14.Signal=GPIO_Output
PB2/BOOT1.Signal=GPIO_Input
PB3.Signal=SYS_JTDO-SWO
PB6.Signal=I2C1_SCL
PB7.GPIO_Label=SI4688_INTB
PB7.Signal=GPIO_Input
PB8.GPIO_Label=SI4688_RSTB
PB8.Signal=GPIO_Output
PB9.Signal=I2C1_SDA
PC10.Signal=I2S3_CK
PC12.Signal=I2S3_SD
PC13.GPIO_Label=LCD_CS
PC13.Signal=GPIO_Output
PC14/OSC32_IN.GPIO_Label=LCD_RES
PC14/OSC32_IN.Signal=GPIO_Output
PC15/OSC32_OUT.GPIO_Label=LCD_CD
PC15/OSC32_OUT.Signal=GPIO_Output
PC3.Signal=I2S2_SD
PC4.GPIO_Label=ROT_A
PC4.Signal=GPIO_Input
PC5.GPIO_Label=ROT_B
PC5.Signal=GPIO_Input
PC6.Signal=I2S2_MCK
PC7.Signal=I2S3_MCK
PD4.GPIO_Label=CS43L22_RESET
PD4.Signal=GPIO_Output
PE12.Signal=SPI4_SCK
PE14.GPIO_Label=SW2
PE14.Signal=GPIO_Input
PE15.GPIO_Label=SW3
PE15.Signal=GPIO_Input
PE2.GPIO_Label=LED1
PE2.Signal=GPIO_Output
PE3.GPIO_Label=LED2
PE3.Signal=GPIO_Output
PE4.GPIO_Label=LED3
PE4.Signal=GPIO_Output
PE6.Signal=SPI4_MOSI
PE7.Signal=GPIO_Input
PH0/OSC_IN.Signal=RCC_OSC_IN
PH1/OSC_OUT.Signal=RCC_OSC_OUT

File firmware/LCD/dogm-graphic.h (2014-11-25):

#ifndef DOGMGRAPHIC_H_INCLUDED
#define DOGMGRAPHIC_H_INCLUDED

#include <inttypes.h>
#include <string.h>
#include "stm32f4xx_hal.h"
#include "font.h"
#include "compat_avr.h"
#include "main.h"

/*****************************************************************************
 * BEGIN CONFIG BLOCK
 *****************************************************************************/
//Select the display type: DOGS102: 102, DOGM128/DOGL128: 128, DOGM132: 132, DOGXL160: 160
#define DISPLAY_TYPE  102

//Should chip select (CS) be used?
#define LCD_USE_CHIPSELECT  0

//Use Backlight?  (0: no backlight, 1: backlight (on when pin is high), 2: backlight (on when pin is low))
#define LCD_USE_BACKLIGHT   0

/* //A0 Port (CD on DOGS & DOGXL) */
/* #define PORT_A0  PORTD */
/* #define DDR_A0   DDRD */
/* #define PIN_A0   2 */

/* //Reset Port */
/* #define PORT_RST PORTD */
/* #define DDR_RST  DDRD */
/* #define PIN_RST  5 */

/* //Backlight Port */
/* #if LCD_USE_BACKLIGHT != 0 */
/* #define PORT_LED PORTB */
/* #define DDR_LED  DDRB */
/* #define PIN_LED  4 */
/* #endif */

/* //Chip select */
/* #if LCD_USE_CHIPSELECT == 1 */
/* #define PORT_CS  PORTC */
/* #define DDR_CS   DDRC */
/* #define PIN_CS   PORTC0 */
/* #endif */

//SPI routines
//Define a function that initializes  the SPI interface, see below for an example
extern void init_spi_lcd(void);
#define LCD_INIT_SPI() init_spi_lcd()

//Define a function that waits until SPI interface is idle
//#define spi_wait_for_idle() while(! (UCSR1A & _BV(TXC1)));UCSR1A |= _BV(TXC1)
/* #define spi_wait_for_idle() while (!(IORD_ALTERA_AVALON_SPI_STATUS(SPI_LCD_BASE) & ALTERA_AVALON_SPI_STATUS_TRDY_MSK)); */
#define spi_wait_for_idle()

//Define how to write to SPI data register
//#define spi_write(i) UDR1 = i
#define spi_write(i) HAL_SPI_Transmit(&hspi4,&i,1,1000)
/* #define spi_write(i) alt_avalon_spi_command(SPI_LCD_BASE, 0, 1, &i, 0, NULL, 0); */

//Define this if LCD Output should continue in next line when reaching edge of display
//Used for all outputs. To enable this feature for text only, use the appropriate flag in font.h
#define LCD_WRAP_AROUND  1

//Include graphic functions, i.e. lcd_draw_image_P, lcd_draw_image_xy_P, lcd_clear_area ? 
#define LCD_INCLUDE_GRAPHIC_FUNCTIONS  1

/*Example SPI setup (Atmega162)
 *init spi: msb first, update on falling edge , read on rising edge, 9 MHz
 *void init_spi_lcd() {
 *  SPCR = 0 << SPIE | 1 << SPE | 0 << DORD | 1 << MSTR | 1 << CPOL | 1 << CPHA | 0 << SPR1 | 0 << SPR0;
 *  SPSR = 1 << SPI2X;
 *  SPDR = LCD_NOP; //Do not use 0 here, only LCD_NOP is allowed!
 *  }
 */
/*****************************************************************************
 * END CONFIG BLOCK
 *****************************************************************************/




/*****************************************************************************
 * Public Functions
 *****************************************************************************/

void lcd_set_backlight(uint16_t val);

//initializes the display in standard settings
//for DOGS, DOGM, DOGL and DOGXL
void lcd_init(uint8_t top_view);

//write data word or command to the LCD
void lcd_data     (uint8_t data);
void lcd_command  (uint8_t cmd);


//Function to read the current position
extern uint8_t lcd_current_page;
extern uint8_t lcd_current_column;
static inline uint8_t lcd_get_position_page(void)   {return lcd_current_page;}
static inline uint8_t lcd_get_position_column(void) {return lcd_current_column;}

//User functions to write raw data from flash
#if LCD_INCLUDE_GRAPHIC_FUNCTIONS >= 1
void lcd_draw_image_P(PGM_P progmem_image, uint8_t pages, uint8_t columns, uint8_t style);
void lcd_draw_image_xy_P(PGM_P progmem_image, uint8_t x, uint8_t y, uint8_t pages, uint8_t columns, uint8_t style);
#endif

void lcd_clear_area(uint8_t pages, uint8_t columns, uint8_t style);
void lcd_clear_area_xy(uint8_t pages, uint8_t columns, uint8_t style, uint8_t page, uint8_t col);


//Move cursor
void lcd_moveto_xy  (uint8_t page, uint8_t column);
void lcd_move_xy    (int8_t pages, int16_t columns);



//Text functions are included in font.c / font.h

/*****************************************************************************
 * LCD Size, based on type selection above
 *****************************************************************************/
#if DISPLAY_TYPE == 160
#define LCD_WIDTH            160 //width of the LCD
#define LCD_HEIGHT           104 //height of the LCD
#define LCD_RAM_PAGES        26  //size of LCD RAM
#define LCD_PIXEL_PER_BYTE   4   //using double pixels
#define LCD_DOUBLE_PIXEL     1   
#endif

#if DISPLAY_TYPE == 132
#define LCD_WIDTH          132 //width of the LCD
#define LCD_HEIGHT         32  //height of the LCD
#define LCD_RAM_PAGES      4   //size of LCD RAM
#define LCD_PIXEL_PER_BYTE 8   //using single pixels
#endif

#if DISPLAY_TYPE == 128
#define LCD_WIDTH          128 //width of the LCD
#define LCD_HEIGHT         64  //height of the LCD
#define LCD_RAM_PAGES      8   //size of LCD RAM
#define LCD_PIXEL_PER_BYTE 8   //using single pixels
#endif

#if DISPLAY_TYPE == 102
#define LCD_WIDTH          102 //width of the LCD
#define LCD_HEIGHT         64  //height of the LCD
#define LCD_RAM_PAGES      8   //size of LCD RAM
#define LCD_PIXEL_PER_BYTE 8   //using single pixels
#endif

/*****************************************************************************
 * Command Codes
 *****************************************************************************/
#if DISPLAY_TYPE == 128 || DISPLAY_TYPE == 132 || DISPLAY_TYPE == 102
#define LCD_DISPLAY_ENABLE    0xAE  //1: Display on/off
#define LCD_START_LINE        0x40  //2: display start line set 
#define LCD_PAGE_ADDRESS      0xB0  //3: Page address set (lower 4 bits select one of the pages)
#define LCD_COL_ADDRESS       0x10  //4: column address 
#define LCD_BOTTOMVIEW        0xA0  //8: select orientation 
#define LCD_DISPLAY_INVERT    0xA6  //9: inverted display
#define LCD_ALL_PIXEL         0xA4  //10: show memory content or switch all pixels on
#define LCD_BIAS              0xA2  //11: lcd bias set
#define LCD_RESET_CMD         0xE2  //14: Reset Controller
#define LCD_SCAN_DIR          0xC0  //15: output mode select (turns display upside-down)
#define LCD_POWER_CONTROL     0x28  //16: power control set 
#define LCD_VOLTAGE           0x20  //17: voltage regulator resistor ratio set 
#define LCD_VOLUME_MODE       0x81  //18: Volume mode set 
#define LCD_NO_OP             0xE3  //22: NOP command
#endif

#if DISPLAY_TYPE == 128 || DISPLAY_TYPE == 132
#define LCD_INDICATOR         0xAC  //19: static indicator (2-byte command)
#define LCD_BOOSTER_SET       0xF8  //20: booster ratio set
#endif

#if DISPLAY_TYPE == 102
#define LCD_ADV_PROG_CTRL     0xFA  //25: advanced program control 
#define LCD_ADV_PROG_CTRL2    0x10  //25: advanced program control 
#endif
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
